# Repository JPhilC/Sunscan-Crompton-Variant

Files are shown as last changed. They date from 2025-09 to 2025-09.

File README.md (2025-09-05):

# Sunscan-Crompton-Variant
Inspired by the Staros Project's Sunscan spectro heliograph my version uses second hand M39 75mm enlarger lenses and a stopped down 50mm objective lens from an old Skywatcher 9 x 50 finder scope.

Details of the official Sunscan project can be found [here](https://www.sunscan.net/) and I strongly recommend you read through everything they have on there if you want to understand what I put up here. SUNSCAN © 2024 by Staros Projects.

The primary difference between the official Sunscan and this one are:

- M39 enlarger lenses for the collimator and the camera lenses
- 50mm objective lens from a Skywatcher 9 x 50 finder scope
- Use of an RS60-L Manual Trimming Station Platform Linear Stage Tuning Sliding Table φ60mm (as described on ebay) for the grating holder

I had previously bought the turntable in preparation for an attempt at the PVC spectro heligraph (https://github.com/terawats/PVC_Spectroheliograph) so I decided to incorporate that too. This also necessitated a different approach to how the defraction grating is adjusted. It is now adjusted using a single M3 machine screw accessed through the infinity window behind the grating holder.

The M39 enlarger lenses I picked up off ebay for around £20 each, I have three to choose from:

- Schneider - Kreuznach 75mm f1:4.0 (used for the collimator)
- Hoya Super EL 75mm f1:4.5 (used for the camera lens)
- Perfex 90mm F4.5 Anastigmat (alternative camera lens near to Sunscan 100mm focal length)

The model is created in the Autodesk Fusion (Personal use) version. Most of the print files are on here, the three that you will still need to get from the original Sunscan 3D prints are the two part mirror holder and the Raspberry Pi power button. A complete list of the components used is in the [Components.md](Components.md) file along with a link to the Sunscan print file page.

Fasteners and inserts are mostly M2, M3 or M4 either cap head socket screws or button head screws. If you follow the [Sunscan assembly instructions](https://www.sunscan.net/build/1.-assembly-instructions/) you will get a good idea of what is needed. Instead of assembling their optical components you will need to screw the enlarger lenses into the M39 focus tubes and assembly the objective lens sub-assembly. There are three videos in the videos folder that show how the collator sub assembly, the objective lens sub assembly and the focuser sub assembly are put together.

I used M2, M3 and M4 heat set inserts for the parts that need to be taken apart and put back together again. The RPi case and camera case use M2 inserts and screws where as on the Sunscan they use self tapping screws.

The electronics are all identical to the original Sunscan project, as is the software I use. You can follow the instructions on the Sunscan site for installing the Raspberry Pi OS and configuring and adjusting the device.

A complete list of the parts that I purchased is in the [Partslist.md](Partslist.md) file along with links to where I bought them and the cost. The total cost of my version was around £600 including a portion of the cost of the 3D printer and filament.

Finally a big thank you to [Staros Projects](https://staros-projects.org/en/index.html) for creating the Sunscan project and making all the information available for free. I would not have been able to build this without their work.

|Staros Projects Logo (https://staros-projects.org/en/sunscan.html)|Sunscan Logo (https://www.sunscan.net/)|
|---|---|

## Images

### The completed Crompton variant looks like this:

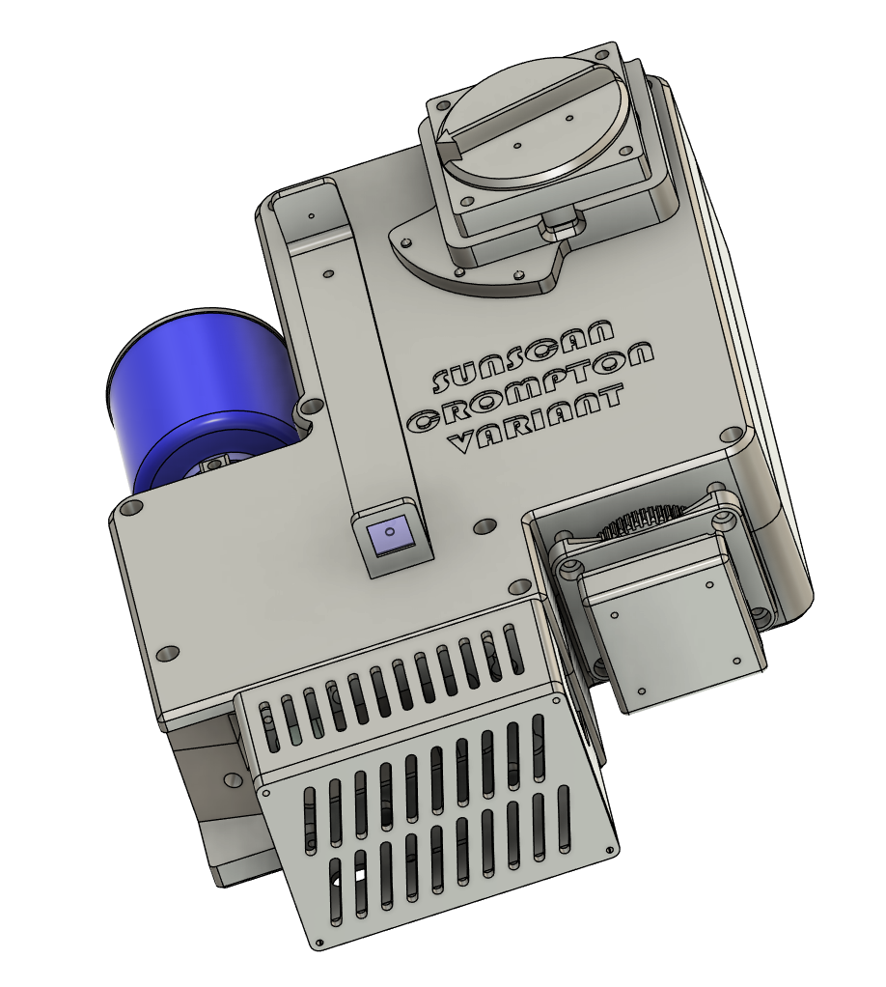
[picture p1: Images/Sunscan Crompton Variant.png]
Image of Sunscan Crompton Variant


### Without the top cover.

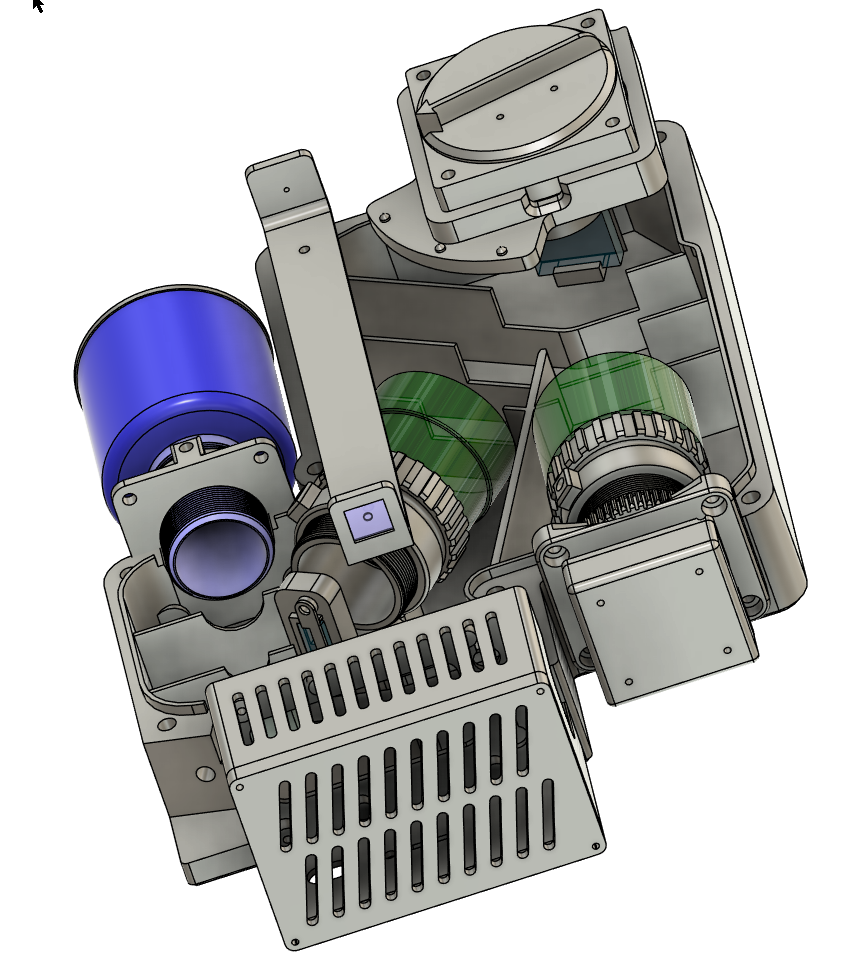
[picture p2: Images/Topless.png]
With the top removed


### First light mounted on a Skywatcher Synscan AZ mount.

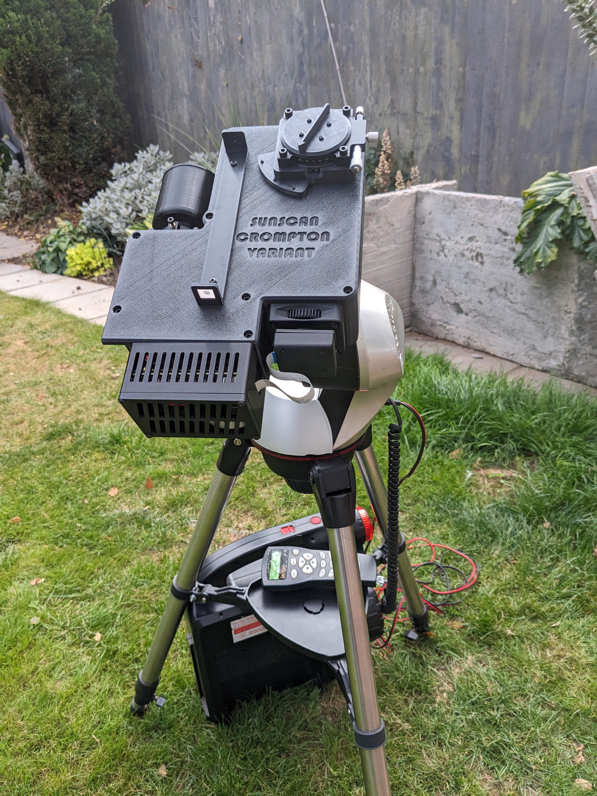
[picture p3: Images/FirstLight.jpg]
First Light


### First images captured on a less than perfect day. Patchy clouds meant that I couldn't quite get the focus right or the exposure.

#### Ha Image

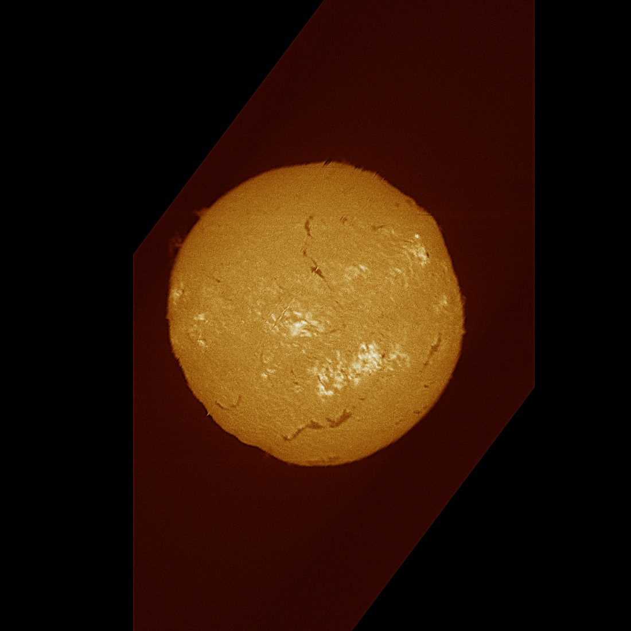
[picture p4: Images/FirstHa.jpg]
Ha Image


#### Artificial eclipse

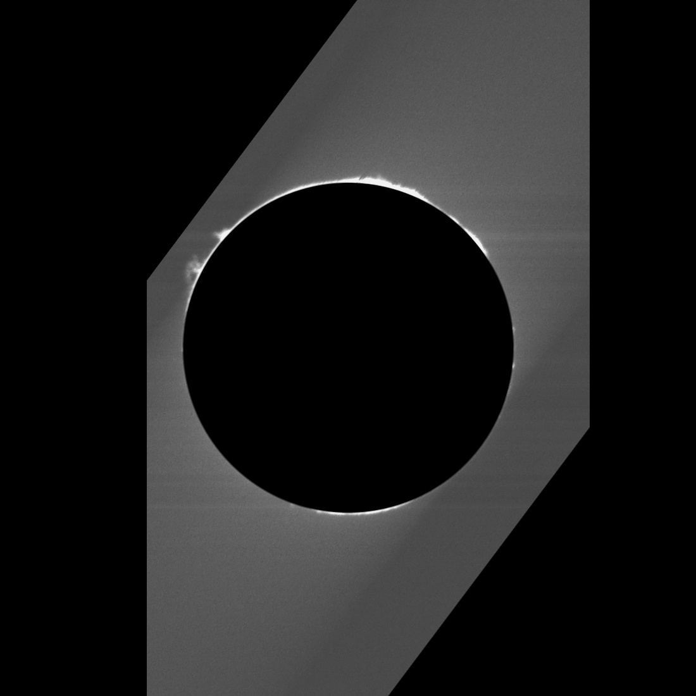
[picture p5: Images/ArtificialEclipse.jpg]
Artificial eclipse
]

#### Screen shot showing Ha Line in mono

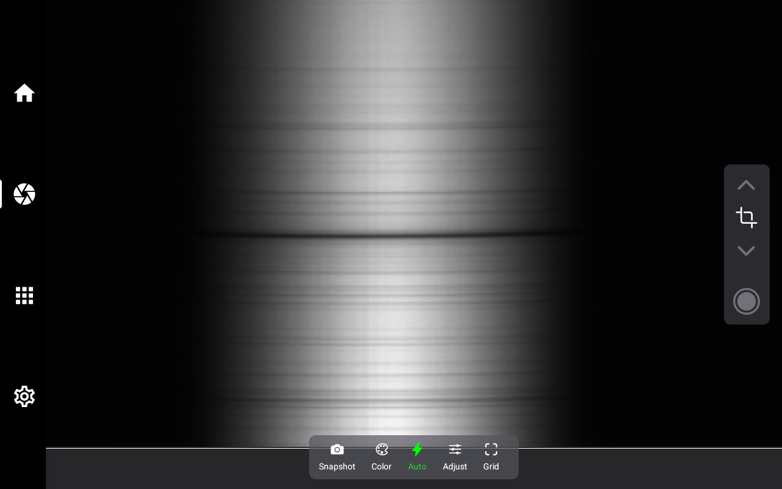
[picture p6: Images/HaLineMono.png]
Screen shot showing Ha Line in mono


and in colour

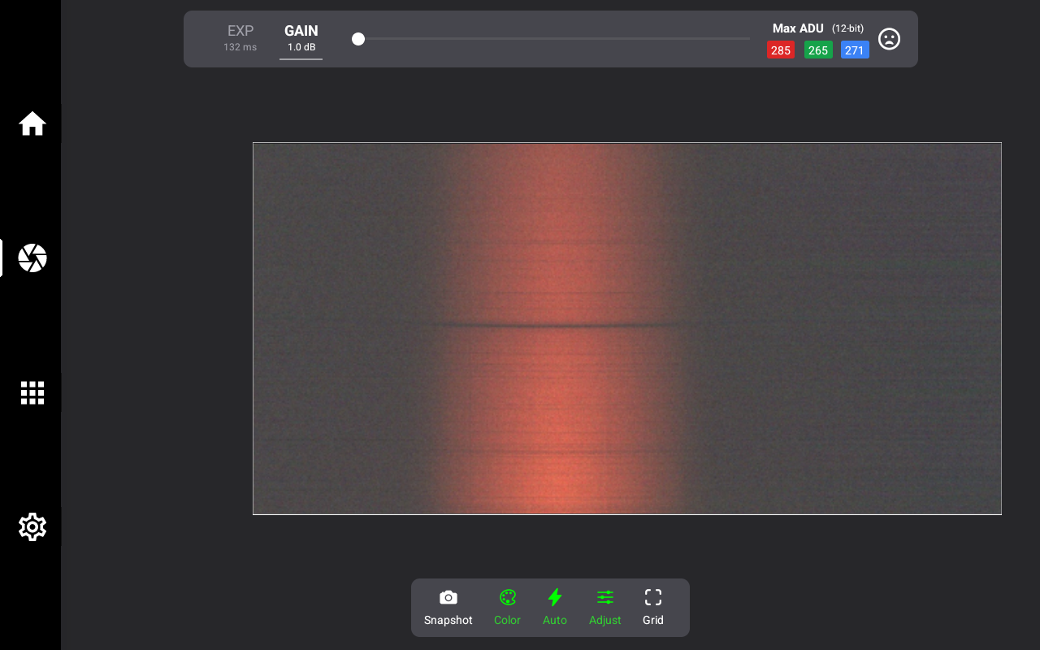
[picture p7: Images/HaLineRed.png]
Sceen shot showing Ha Line in colour


## License

The Sunscan licence page is [here](https://www.sunscan.net/the-sunscan-project/license).

This work is licensed under a [Creative Commons Attribution-NonCommercial-ShareAlike 4.0 International License](https://creativecommons.org/licenses/by-nc-sa/4.0/).



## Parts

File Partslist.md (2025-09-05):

## Parts List
The table below shows the items I purchased for my version of the Sunscan spectroheliograph. I have included links to the items where possible. Some of the items I purchased second hand from ebay or Facebook Marketplace so I have not included links for those. The prices shown are what I paid at the time of purchase and may not reflect current prices. The total cost of the project is shown at the bottom of the table. I allocated part of the cost to the project for items that I can use for other projects such as the 3D printer and fastener selections.

In the table below the links next to the items from Shelyak take you to the complete kit for the standad Sunscan. You need to contact them to order just the bits you want.

|Item description|Source|Link|Cost|Project cost|
|---|---|---|---|---|
|Bambu A1 + 0.5 Hardened Nozzle (for PETG CF)|Bambu Lab|[Bambu Labs Link](https://uk.store.bambulab.com/products/a1)|£271.98|£70.00|
|Sunlu High Speed Matte PETG 1.75mm filament|Bambu Lab|[Sunlu ebay store](https://www.ebay.co.uk/itm/365282877731?var=635040157287)|£13.44|£13.44|
|2400g/mm Defraction Grating VIS 25x25mm|Shelyak|[Suncan kit](https://www.shelyak.com/produit/optical-kit-for-sunscan-spectroheliograph/?lang=en#composition-produit)|170.00 €||
|2 Position Slit|Shelyak|[Suncan kit](https://www.shelyak.com/produit/optical-kit-for-sunscan-spectroheliograph/?lang=en#composition-produit)|61.00 €||
|Mirror 23x16x5mm plane|Shelyak|[Suncan kit](https://www.shelyak.com/produit/optical-kit-for-sunscan-spectroheliograph/?lang=en#composition-produit)|39.00 €||
|Shelyak Total including shipping|Shelyak||295.52 €|£257.07|
|Import charges for Shelyak order|FedEx|||£63.59|
|Perfex 90mm F4.5 Anastigmat M39 Enlarger Lens|ebay|ebay (used)|£19.99|£19.99|
|75mm Enlarging Lenses Schneider & Hoya (2 lenses)|ebay|ebay (used)|£23.99|£23.99|
|RS60L Manual Trimming Station Linear Stage Sliding Table 60mm Displacement|ebay||£37.33|£37.33|
|Meade 1.25" Series 4000 ND96 Moon Filter|ebay|ebay (used)|£10.72|£10.72|
|Nylon Standoff Assortment|Amazon|[Amazon Link](https://www.amazon.co.uk/dp/B0839HM1WX?ref=ppx_yo2ov_dt_b_fed_asin_title)|£4.08|£4.08|
|1260 Pcs M2, M3, M4 Hex Socket Head Cap Screw Selection|Amazon|[Amazon Link](https://www.amazon.co.uk/dp/B0CZSW8S66?ref=ppx_yo2ov_dt_b_fed_asin_title)|£9.98|£2.00|
|308 Pcs Thread Inserts M2, M2.5, M3, M4, M5, M6|Amazon|[Amazon Link](https://www.amazon.co.uk/dp/B0CZN4JRF8?ref=ppx_yo2ov_dt_b_fed_asin_title)|£13.99|£3.50|
|720 Pcs M2, M3, M4 Hex Button Head Screw Selection|Amazon|[Amazon Link](https://www.amazon.co.uk/dp/B0DM93GPR7?ref=ppx_yo2ov_dt_b_fed_asin_title)|£7.99|£2.00|
|Raspberry Pi 4 4GB RAM|FB Marketplace||£45.00|£45.00|
|Geekpi Raspberry Pi 4 Extreme Cooling Fan Kit|ebay|[Ebay listing](https://www.ebay.co.uk/itm/316591822737)|£11.16|£11.16|
|Raspberry Pi HQ Camera Module CSI-2|ebay|[ebay listing](https://www.ebay.co.uk/itm/395408733275)|£30.28|£30.28|
|SanDisk 128GB Extreme microSDXC card|Amazon|[Amazon link](https://www.amazon.co.uk/dp/B09X7BK27V?ref=ppx_yo2ov_dt_b_fed_asin_title)|£12.99|£12.99|
||||||
|||||**£607.14**|

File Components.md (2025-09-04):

The following is a list of the component print files I used to make my version of the Sunscan spectro heliograph. In addition to these you will need the two part mirror holder and the Raspberry Pi power button from the original Sunscan project.

Generally if there is a thread involved anywhere I print with 0.16 mm layer height, everything else would be 0.2 mm layer height. I used black Sunlu PETG Matte on a Bambu Labs A1 printer to print my SHG.

| Component Name | Image Preview | Download Link |
|---|---|---|
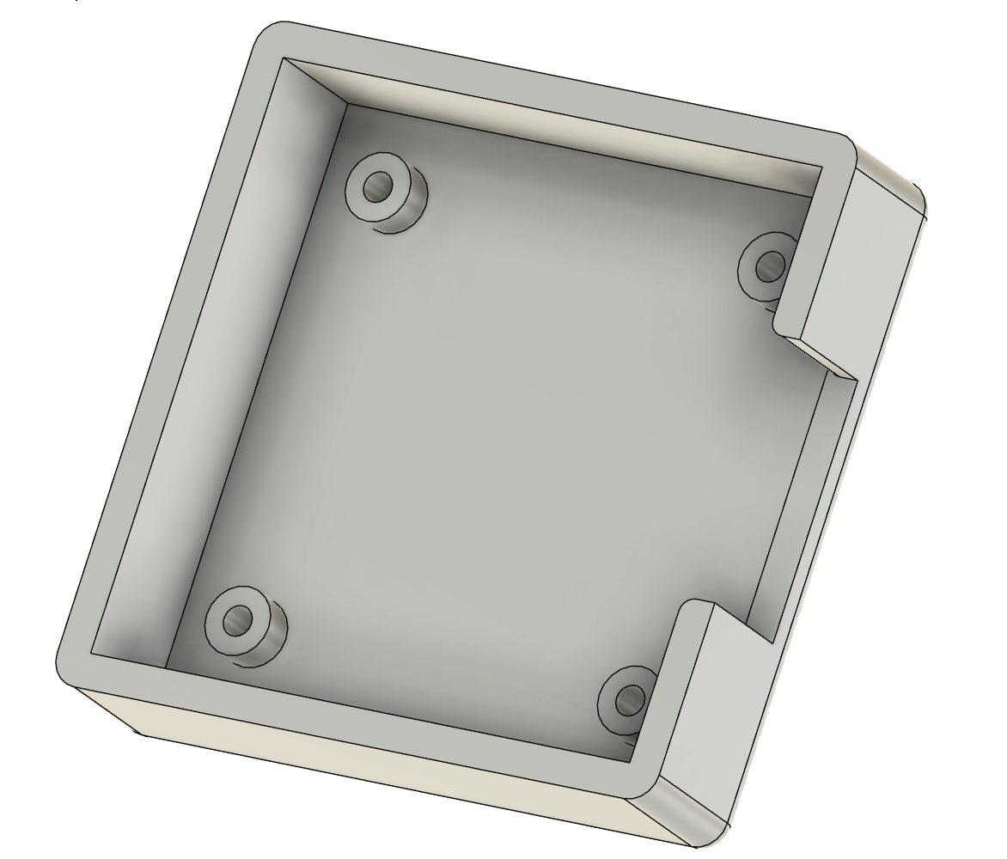
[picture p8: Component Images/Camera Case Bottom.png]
Camera Case Bottom
| Camera Case Bottom |  | [Download Camera Case Bottom.3mf](https://github.com/JPhilC/Sunscan-Crompton-Variant/raw/main/Print%20Files/Camera%20Case%20Bottom.3mf) |
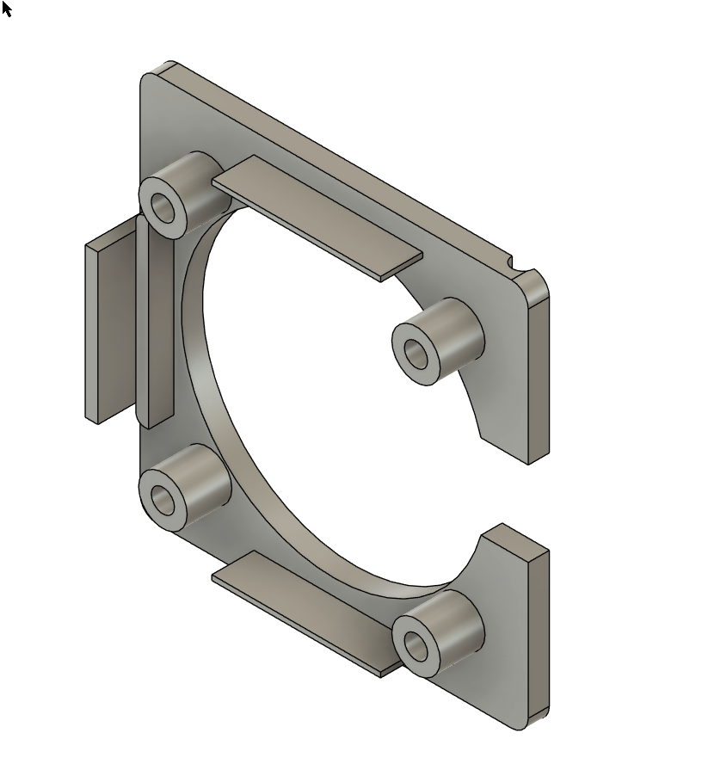
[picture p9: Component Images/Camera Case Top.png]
Camera Case Top
| Camera Case Top |  | [Download Camera Case Top.3mf](https://github.com/JPhilC/Sunscan-Crompton-Variant/raw/main/Print%20Files/Camera%20Case%20Top.3mf) |
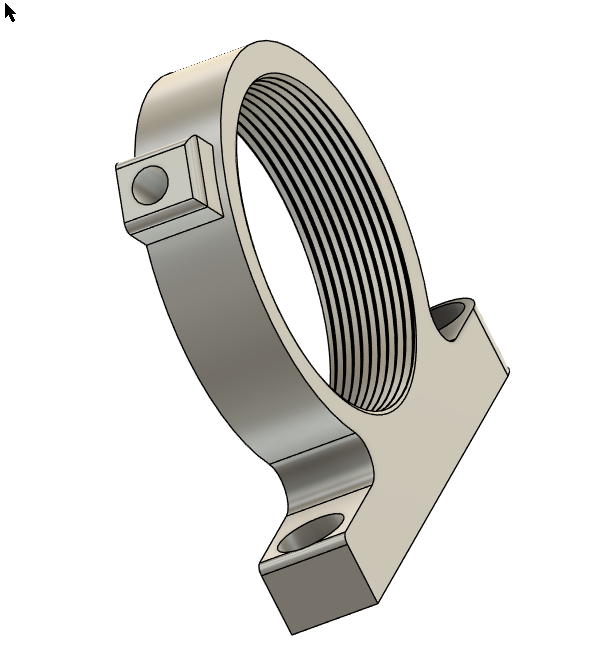
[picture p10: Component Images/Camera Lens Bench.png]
Camera Lens Bench
| Camera Lens Bench |  | [Download Camera Lens Bench.3mf](https://github.com/JPhilC/Sunscan-Crompton-Variant/raw/main/Print%20Files/Camera%20Lens%20Bench.3mf) |
| Cap Filter Holder | Cap Filter Holder | [Download Cap Filter Holder.3mf](https://github.com/JPhilC/Sunscan-Crompton-Variant/raw/main/Print%20Files/Cap%20Filter%20Holder.3mf) |
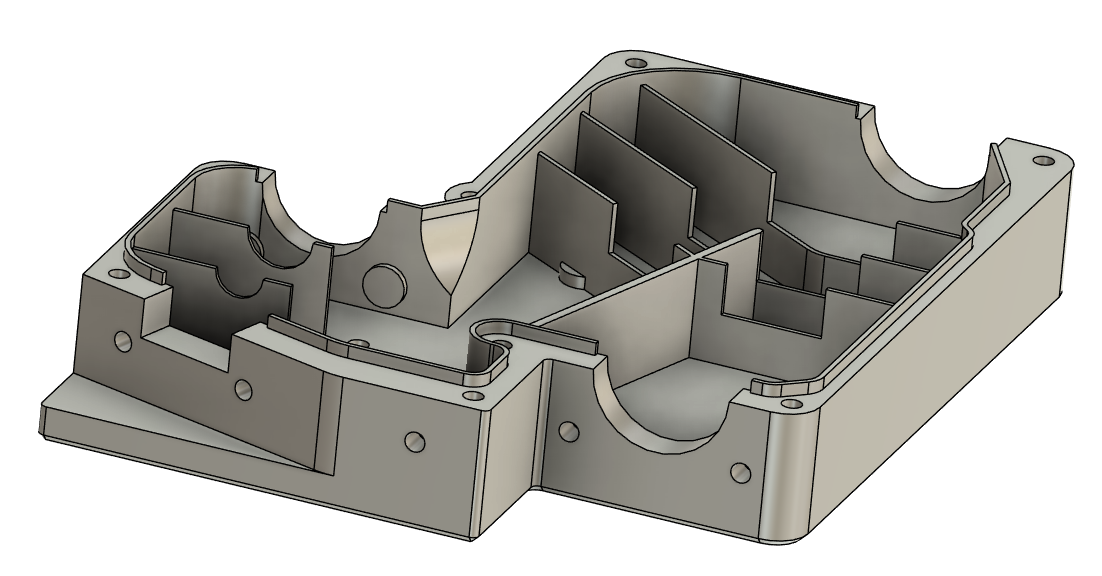
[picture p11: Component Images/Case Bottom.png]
Case Bottom
| Case Bottom |  | [Download Case Bottom.3mf](https://github.com/JPhilC/Sunscan-Crompton-Variant/raw/main/Print%20Files/Case%20Bottom.3mf) |
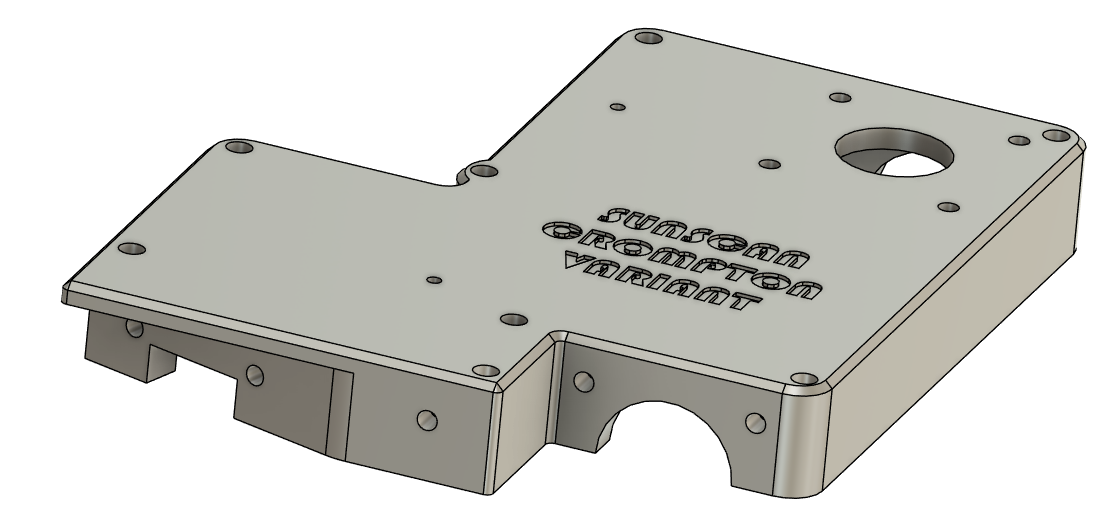
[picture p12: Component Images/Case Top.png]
Case Top
| Case Top |  | [Download Case Top.3mf](https://github.com/JPhilC/Sunscan-Crompton-Variant/raw/main/Print%20Files/Case%20Top.3mf) |
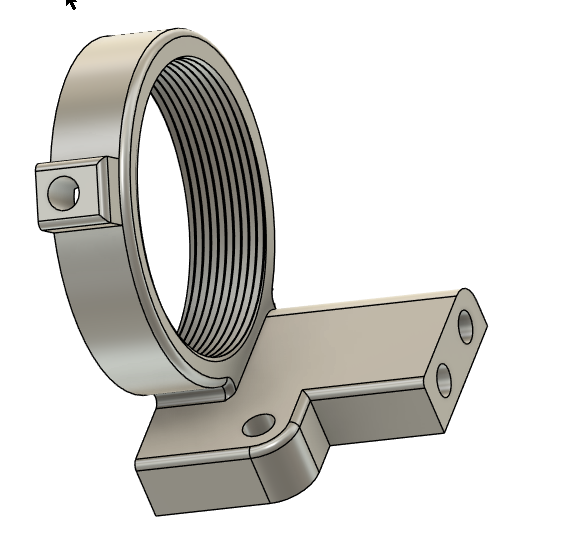
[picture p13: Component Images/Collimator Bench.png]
Collimator Bench
| Collimator Bench |  | [Download Collimator Bench.3mf](https://github.com/JPhilC/Sunscan-Crompton-Variant/raw/main/Print%20Files/Collimator%20Bench.3mf) |
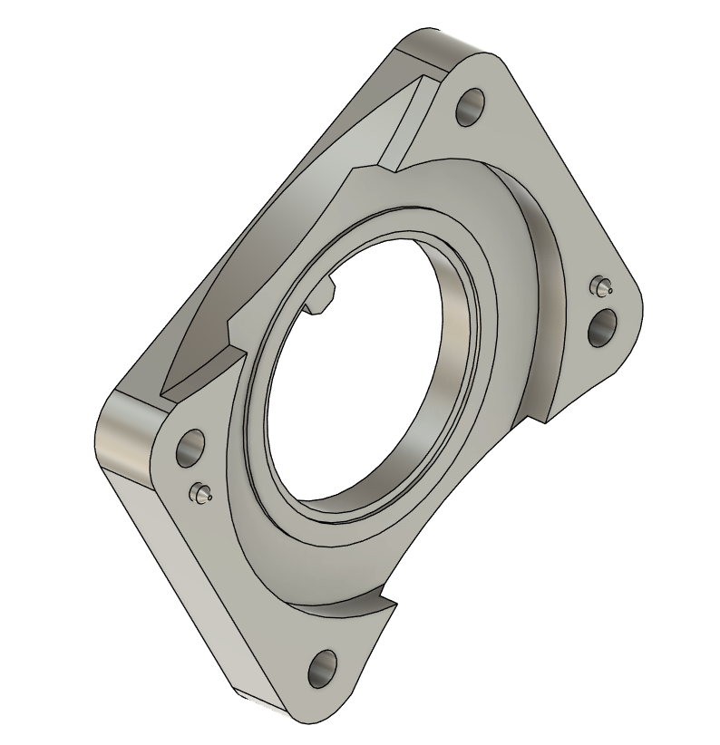
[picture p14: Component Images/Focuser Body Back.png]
Focuser Body Back
| Focuser Body Back |  | [Download Focuser Body Back.3mf](https://github.com/JPhilC/Sunscan-Crompton-Variant/raw/main/Print%20Files/Focuser%20Body%20Back.3mf) |
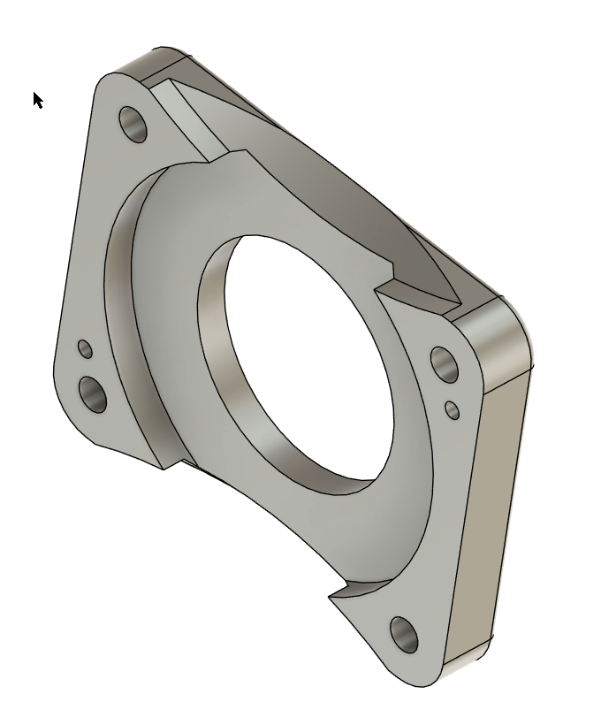
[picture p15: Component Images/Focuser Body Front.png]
Focuser Body Front
| Focuser Body Front |  | [Download Focuser Body Front.3mf](https://github.com/JPhilC/Sunscan-Crompton-Variant/raw/main/Print%20Files/Focuser%20Body%20Front.3mf) |
| Focuser CS Adapter | Focuser CS Adapter | [Download Focuser CS Adapter.3mf](https://github.com/JPhilC/Sunscan-Crompton-Variant/raw/main/Print%20Files/Focuser%20CS%20Adapter.3mf) |
| Focuser Wheel | Focuser Wheel | [Download Focuser Wheel.3mf](https://github.com/JPhilC/Sunscan-Crompton-Variant/raw/main/Print%20Files/Focuser%20Wheel.3mf) |
| Grating Base (alt) | Grating Base (alt) | [Download Grating Base (alt).3mf](https://github.com/JPhilC/Sunscan-Crompton-Variant/raw/main/Print%20Files/Grating%20Base%20%28alt%29.3mf) |
| Grating Base | Grating Base | [Download Grating Base.3mf](https://github.com/JPhilC/Sunscan-Crompton-Variant/raw/main/Print%20Files/Grating%20Base.3mf) |
| Grating Handle | Grating Handle | [Download Grating Handle.3mf](https://github.com/JPhilC/Sunscan-Crompton-Variant/raw/main/Print%20Files/Grating%20Handle.3mf) |
| Grating Holder | Grating Holder | [Download Grating Holder.3mf](https://github.com/JPhilC/Sunscan-Crompton-Variant/raw/main/Print%20Files/Grating%20Holder.3mf) |
| Indicator Disc Spacer | Indicator Disc Spacer | [Download Indicator Disc Spacer.3mf](https://github.com/JPhilC/Sunscan-Crompton-Variant/raw/main/Print%20Files/Indicator%20Disc%20Spacer.3mf) |
| Indicator Disc | Indicator Disc | [Download Indicator Disc.3mf](https://github.com/JPhilC/Sunscan-Crompton-Variant/raw/main/Print%20Files/Indicator%20Disc.3mf) |
| Infinity Hole Cover | Infinity Hole Cover | [Download Infinity Hole Cover.3mf](https://github.com/JPhilC/Sunscan-Crompton-Variant/raw/main/Print%20Files/Infinity%20Hole%20Cover.3mf) |
| Lens Cap | Lens Cap | [Download Lens Cap.3mf](https://github.com/JPhilC/Sunscan-Crompton-Variant/raw/main/Print%20Files/Lens%20Cap.3mf) |
| M31 Interface block | M31 Interface block | [Download M31 Interface block.3mf](https://github.com/JPhilC/Sunscan-Crompton-Variant/raw/main/Print%20Files/M31%20Interface%20block.3mf) |
| M39 Lens Focus Tube | M39 Lens Focus Tube | [Download M39 Lens Focus Tube.3mf](https://github.com/JPhilC/Sunscan-Crompton-Variant/raw/main/Print%20Files/M39%20Lens%20Focus%20Tube.3mf) |
| ND Filter Holder | ND Filter Holder | [Download ND Filter Holder.3mf](https://github.com/JPhilC/Sunscan-Crompton-Variant/raw/main/Print%20Files/ND%20Filter%20Holder.3mf) |
| Objective Bench | Objective Bench | [Download Objective Bench.3mf](https://github.com/JPhilC/Sunscan-Crompton-Variant/raw/main/Print%20Files/Objective%20Bench.3mf) |
| Objective Focus Tube | Objective Focus Tube | [Download Objective Focus Tube.3mf](https://github.com/JPhilC/Sunscan-Crompton-Variant/raw/main/Print%20Files/Objective%20Focus%20Tube.3mf) |
| Objective Lens Housing | Objective Lens Housing | [Download Objective Lens Housing.3mf](https://github.com/JPhilC/Sunscan-Crompton-Variant/raw/main/Print%20Files/Objective%20Lens%20Housing.3mf) |
| Objective Spacer Ring | Objective Spacer Ring | [Download Objective Spacer Ring.3mf](https://github.com/JPhilC/Sunscan-Crompton-Variant/raw/main/Print%20Files/Objective%20Spacer%20Ring.3mf) |
| RPi Case Bottom | RPi Case Bottom | [Download RPi Case Bottom.3mf](https://github.com/JPhilC/Sunscan-Crompton-Variant/raw/main/Print%20Files/RPi%20Case%20Bottom.3mf) |
| RPi Case Top | RPi Case Top | [Download RPi Case Top.3mf](https://github.com/JPhilC/Sunscan-Crompton-Variant/raw/main/Print%20Files/RPi%20Case%20Top.3mf) |
| Slit Bench | Slit Bench | [Download Slit Bench.3mf](https://github.com/JPhilC/Sunscan-Crompton-Variant/raw/main/Print%20Files/Slit%20Bench.3mf) |
| Slit Cover | Slit Cover | [Download Slit Cover.3mf](https://github.com/JPhilC/Sunscan-Crompton-Variant/raw/main/Print%20Files/Slit%20Cover.3mf) |
| Solar Finder Frame | Solar Finder Frame | [Download Solar Finder Frame.3mf](https://github.com/JPhilC/Sunscan-Crompton-Variant/raw/main/Print%20Files/Solar%20Finder%20Frame.3mf) |
| Solar Finder Target | Solar Finder Target | [Download Solar Finder Target.3mf](https://github.com/JPhilC/Sunscan-Crompton-Variant/raw/main/Print%20Files/Solar%20Finder%20Target.3mf) |
| SynScan AZ Bracket | SynScan AZ Bracket | [Download SynScan AZ Bracket.3mf](https://github.com/JPhilC/Sunscan-Crompton-Variant/raw/main/Print%20Files/SynScan%20AZ%20Bracket.3mf) |
| Turntable Platform | Turntable Platform | [Download Turntable Platform.3mf](https://github.com/JPhilC/Sunscan-Crompton-Variant/raw/main/Print%20Files/Turntable%20Platform.3mf) |
| Vixen Bar | Vixen Bar | [Download Vixen Bar.3mf](https://github.com/JPhilC/Sunscan-Crompton-Variant/raw/main/Print%20Files/Vixen%20Bar.3mf) |

You can find the Sunscan project 3D print files [here](https://www.sunscan.net/build/list-of-parts/3d-printing/).

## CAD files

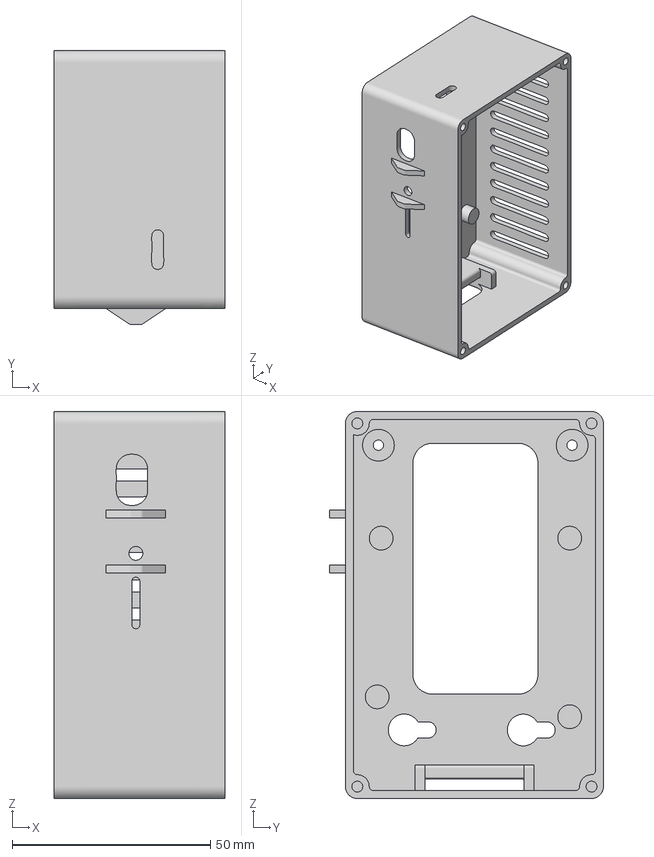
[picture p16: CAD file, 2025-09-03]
Print Files/RPi Case bottom.3mf
43.0 x 69.0 x 97.5 mm

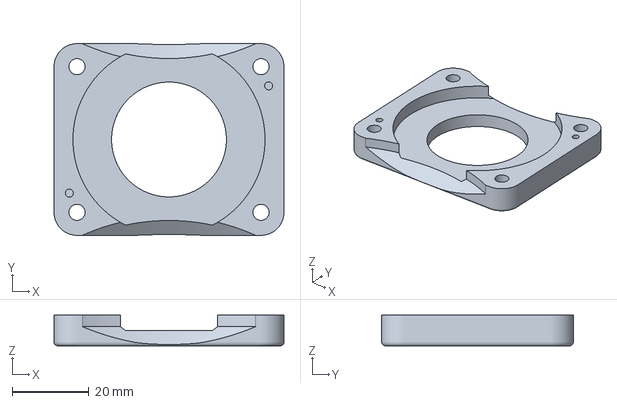
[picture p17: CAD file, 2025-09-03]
Print Files/Focuser Body Front.3mf
60.0 x 50.0 x 8.00 mm

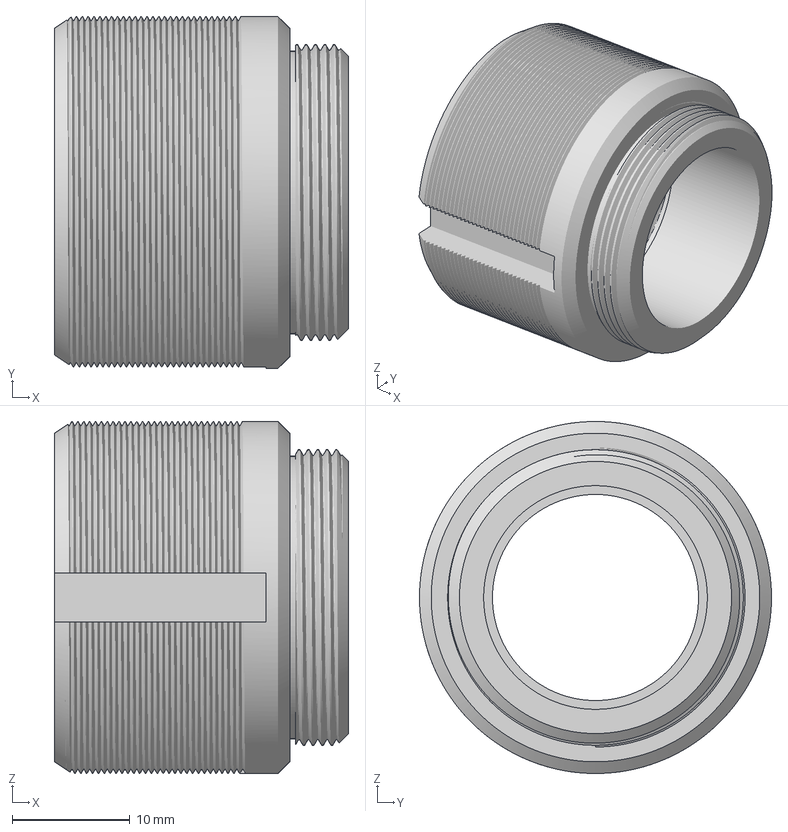
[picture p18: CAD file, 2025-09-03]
Print Files/Focuser CS Adapter.3mf
25.0 x 29.9 x 29.9 mm

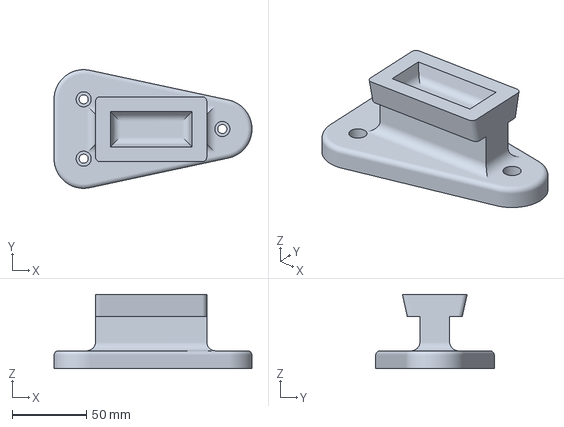
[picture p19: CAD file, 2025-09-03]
Print Files/Vixen Bar.3mf
133.4 x 80.0 x 50.0 mm

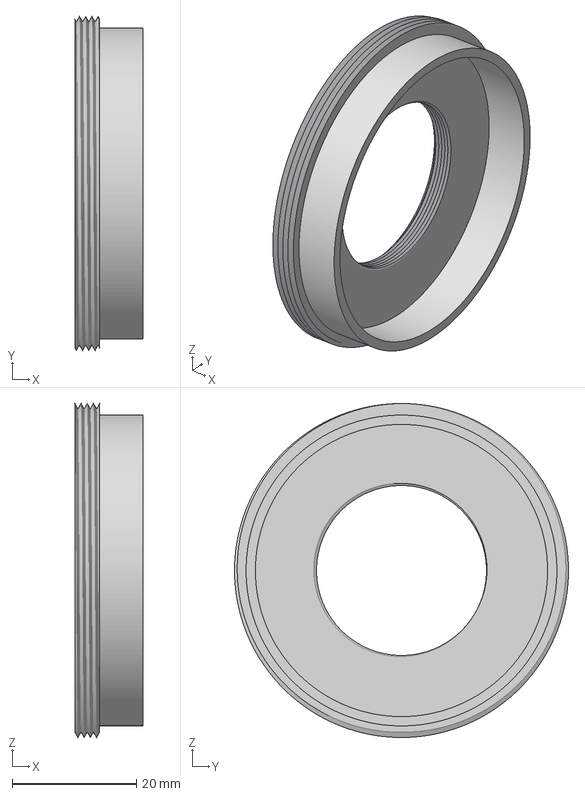
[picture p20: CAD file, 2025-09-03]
Print Files/ND Filter Holder.3mf
11.0 x 53.7 x 53.7 mm

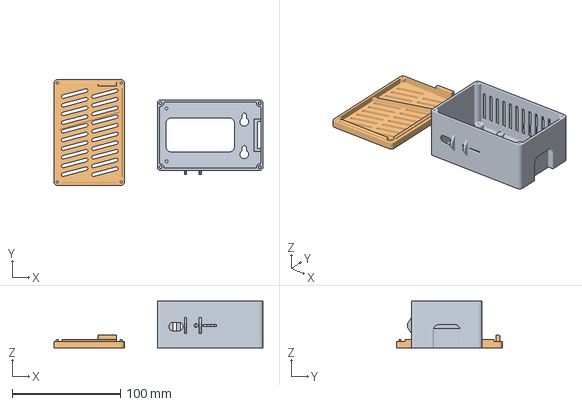
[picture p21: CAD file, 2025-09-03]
Print Files/RPi Case top.3mf
192.8 x 97.5 x 43.0 mm
RPi Case Bottom
RPi Case Top

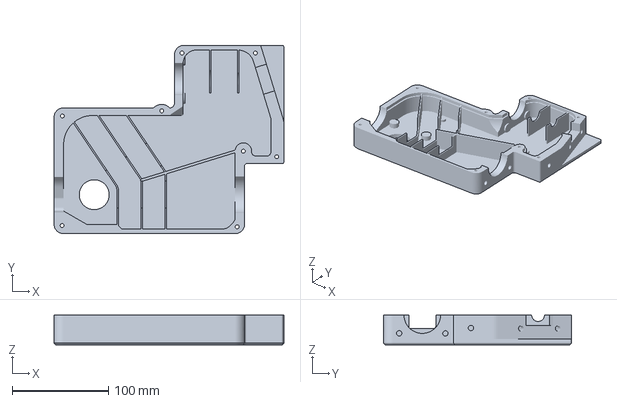
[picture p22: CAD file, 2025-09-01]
Print Files/Case top.3mf
238.8 x 195.6 x 31.0 mm

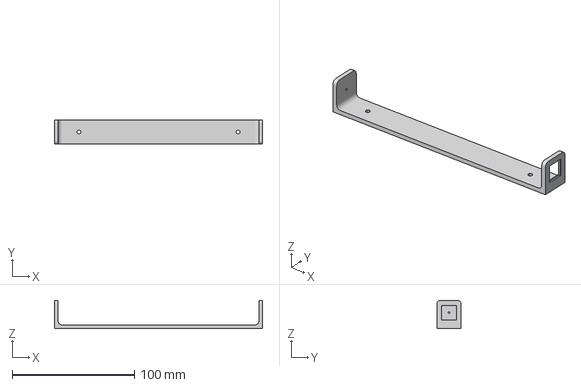
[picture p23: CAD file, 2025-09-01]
Print Files/Solar finder frame.3mf
170.0 x 20.0 x 23.0 mm

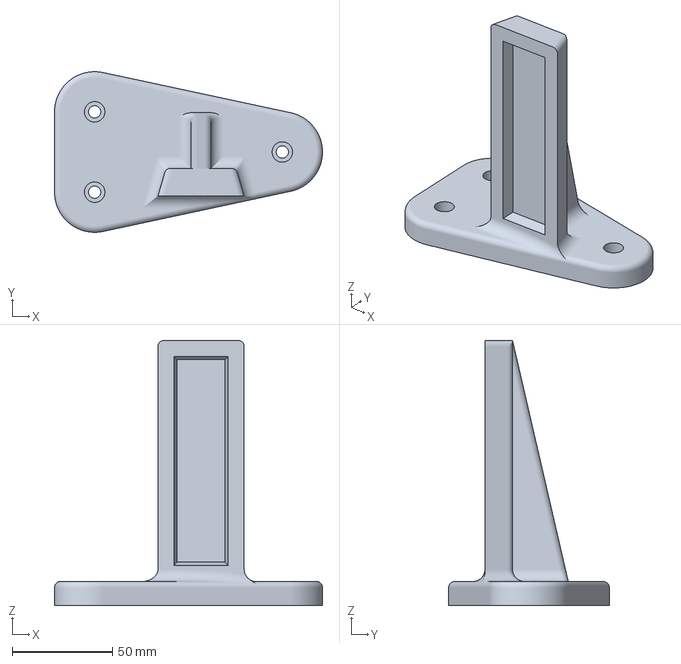
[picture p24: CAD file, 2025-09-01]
Print Files/SynScan AZ Bracket.3mf
133.4 x 80.0 x 132.0 mm

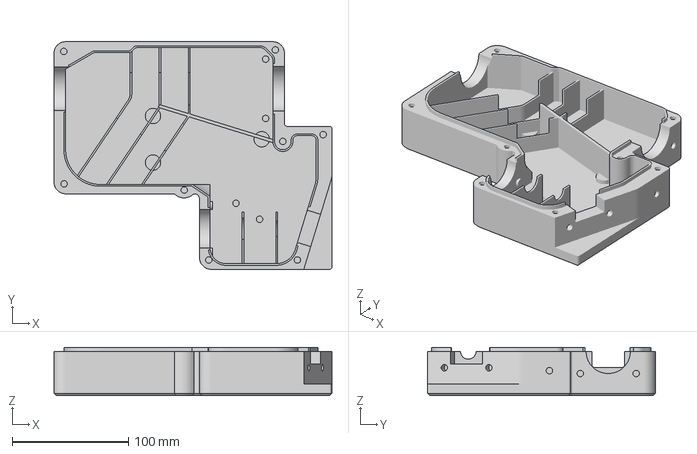
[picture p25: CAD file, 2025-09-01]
Print Files/Case bottom.3mf
238.8 x 195.6 x 41.5 mm

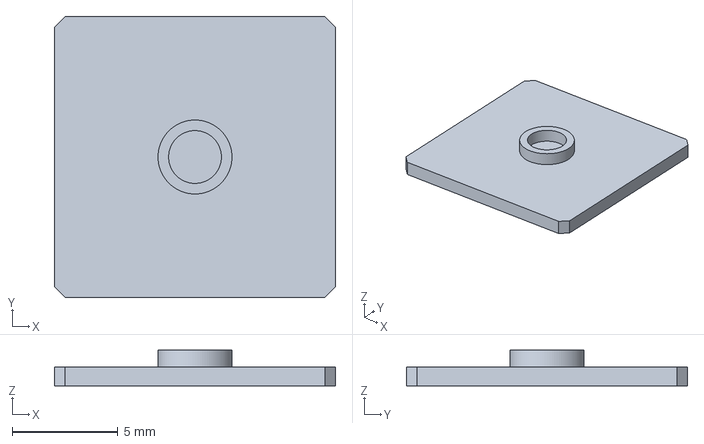
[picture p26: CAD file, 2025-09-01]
Print Files/Lens Cap.3mf
13.3 x 13.3 x 1.70 mm

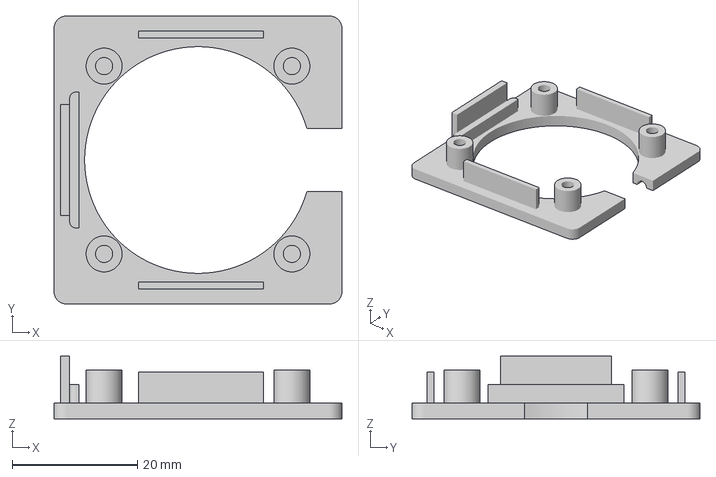
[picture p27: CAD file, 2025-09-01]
Print Files/Camera Case Top.3mf
46.0 x 46.0 x 10.0 mm

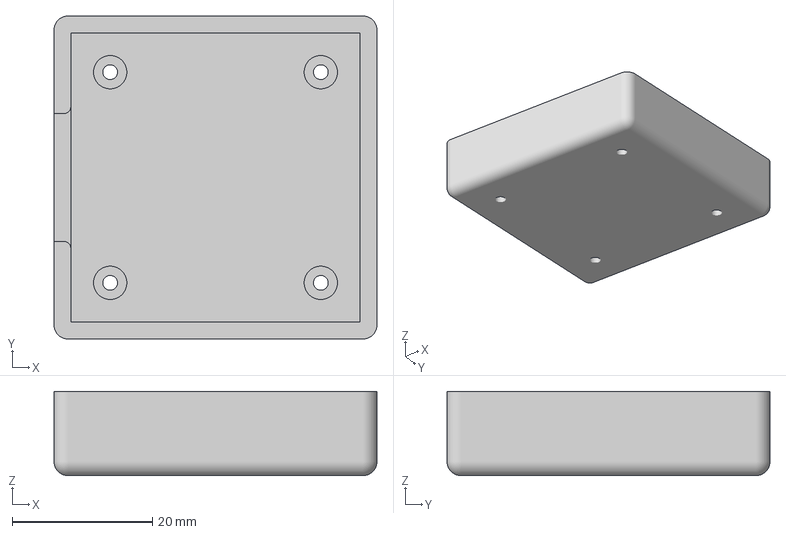
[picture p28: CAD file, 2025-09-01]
Print Files/Camera Case Bottom.3mf
46.0 x 46.0 x 12.0 mm

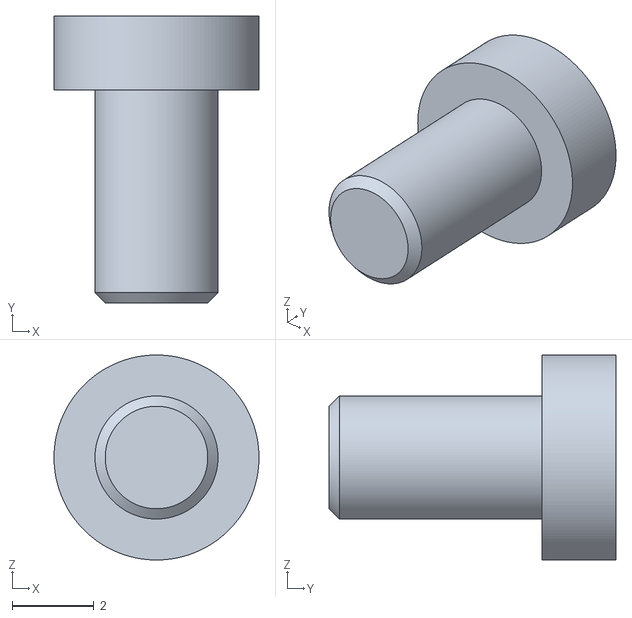
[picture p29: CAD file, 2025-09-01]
Print Files/RPi Power Button.stl
5.00 x 7.00 x 5.00

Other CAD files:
Print Files/Solar Finder Target.3mf
Print Files/Focuser Wheel.3mf
Print Files/Grating handle.3mf
Print Files/Grating base (alt).3mf
Print Files/Camera Lens Bench.3mf
Print Files/Cap Filter Holder.3mf
Print Files/Collimator Bench.3mf
Print Files/Focuser Body Back.3mf
Print Files/Grating Holder.3mf
Print Files/Grating base.3mf
Print Files/Indicator Disc Spacer.3mf
Print Files/Indicator Disc.3mf
Print Files/Infinity Hole Cover.3mf
Print Files/M31 Interface block.3mf
Print Files/M39 lens focus tube.3mf
Print Files/Objective Bench.3mf
Print Files/Objective Focus tube.3mf
Print Files/Objective Lens Housing.3mf
Print Files/Objective Spacer Ring.3mf
Print Files/Slit Bench.3mf
Print Files/Slit cover.3mf
Print Files/Turntable Platform.3mf

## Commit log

2025-08-26 Initial checking of project artifacts
    Adding project artifacts as of 26 August 2025
    [Block.3mf, CalibrationBlock.3mf, Camera Focus tube.3mf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]
2025-09-01 Adding print files to date
    [Camera Case Bottom.3mf, Camera Case Top.3mf, Case bottom.3mf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]
2025-09-02 Working on component table file
    [Block.3mf, CalibrationBlock.3mf, Camera Lens Bench.3mf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]
2025-09-03 Version 1 ?
    More or less all there.
    [Camera Focus tube.3mf, Focuser Body Front.3mf, Focuser CS Adapter.3mf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]
2025-09-04 Download links
    Attempting to get print file links to act as download links.
2025-09-04 Update README with clearer lens and turntable details
    Clarified the description of the M39 enlarger lenses and adjusted the explanation of the turntable and diffraction grating adjustment.
